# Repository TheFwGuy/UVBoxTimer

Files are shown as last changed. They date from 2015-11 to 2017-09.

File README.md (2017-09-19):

UV Box Timer project

To compile, Set Energia to have the library included and open UVBoxTimer.ino.
This directory should be placed in the main directory where the sketches are
kept.

It is necessary to have these libraries installed in the library directory:

- LCD_protocol_terminal
- LCD_screen
- LiquidCrystal
- SD

Schematics

The schematic used to generate the PCB is under Eagle, UVBoxTimer_g, UVBoxSchematic_r

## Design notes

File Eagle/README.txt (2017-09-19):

The original schematic is under UVBoxTimer.
UVBoxTimer_g is the one created by Roberto in order to prepare the PCB.
So the PCB related schematic is under UVBoxTimer_g, and the schematic is named UVBoxSchematic_r.sch

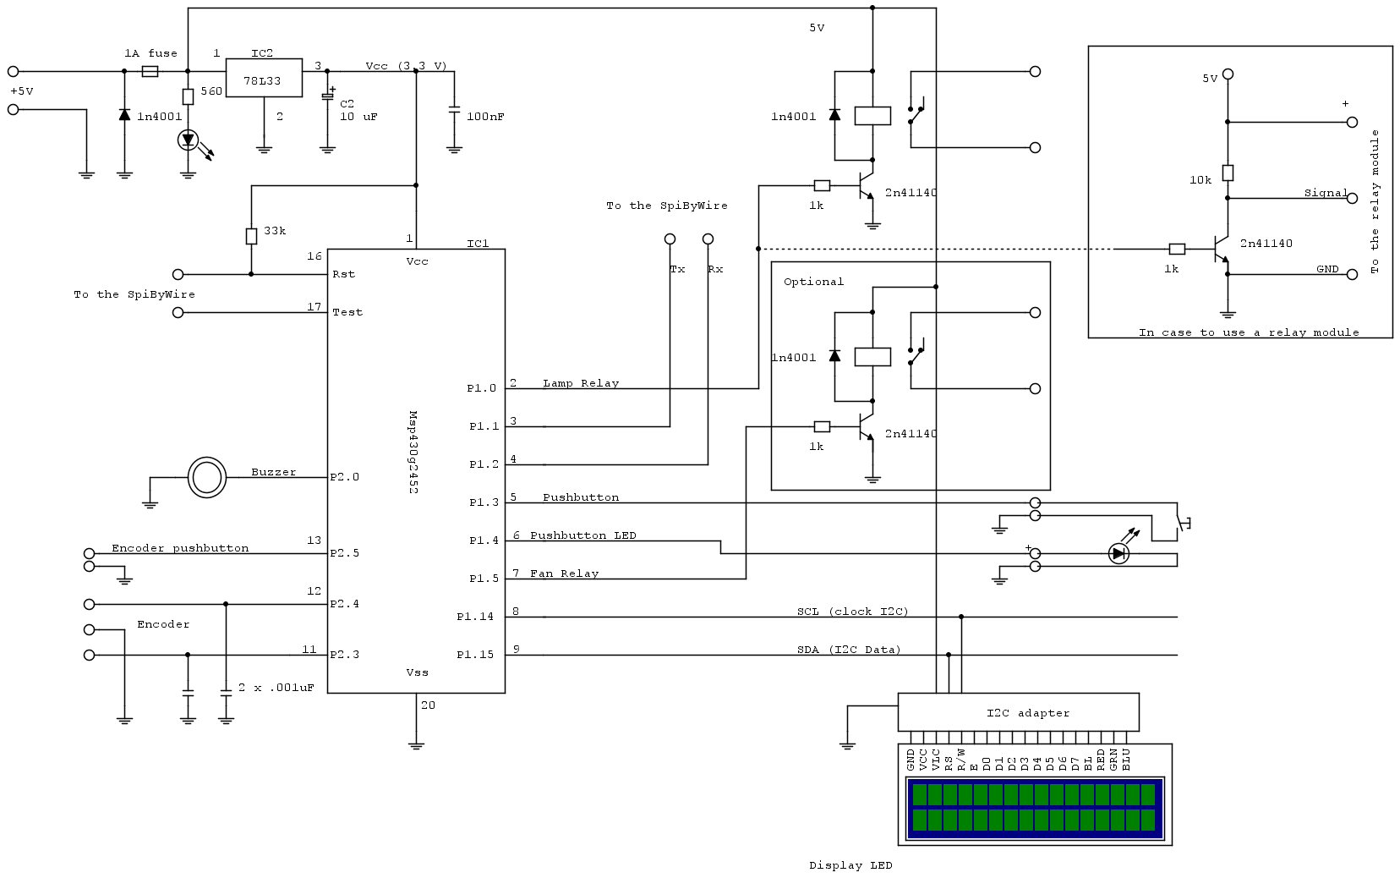
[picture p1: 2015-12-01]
schematic/uvtimer.png

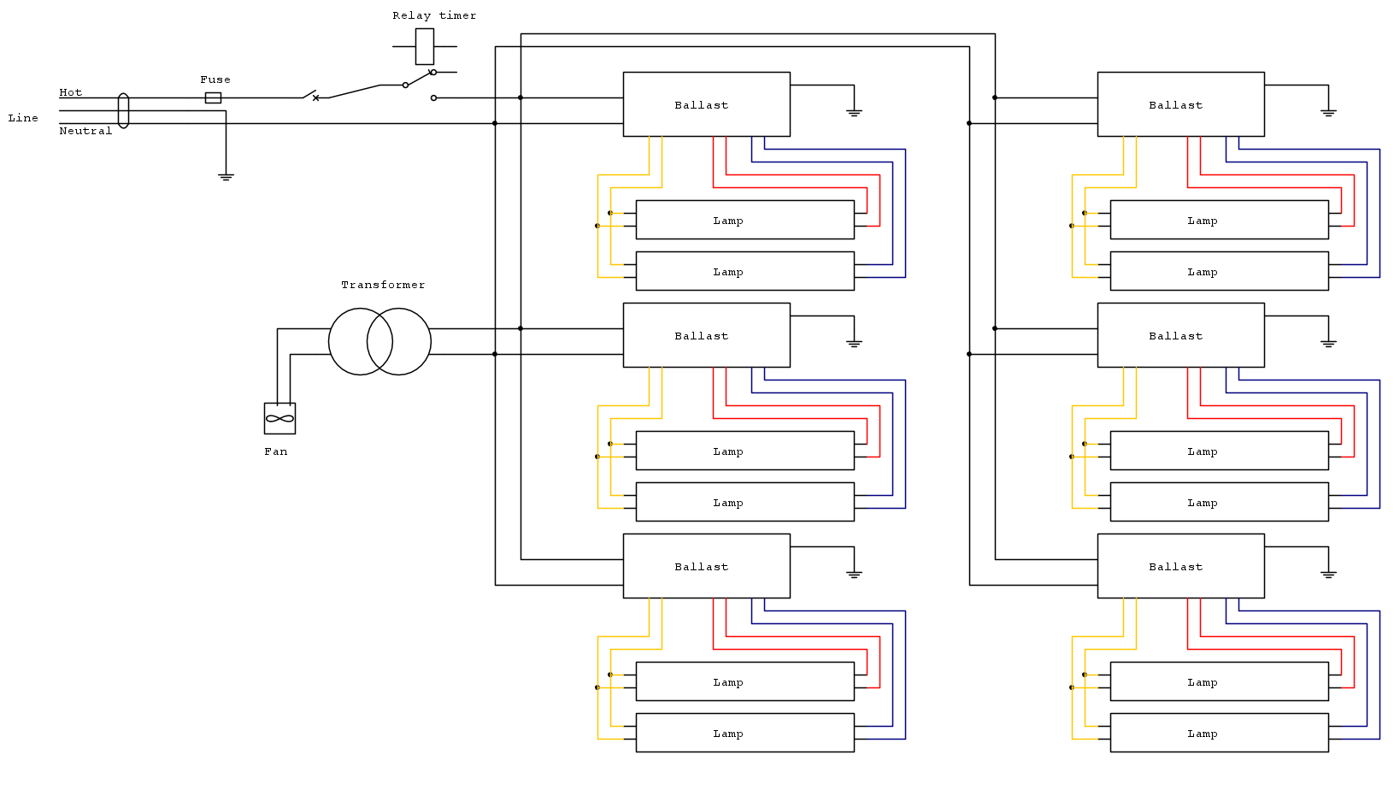
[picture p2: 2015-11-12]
schematic/uvlamps.png

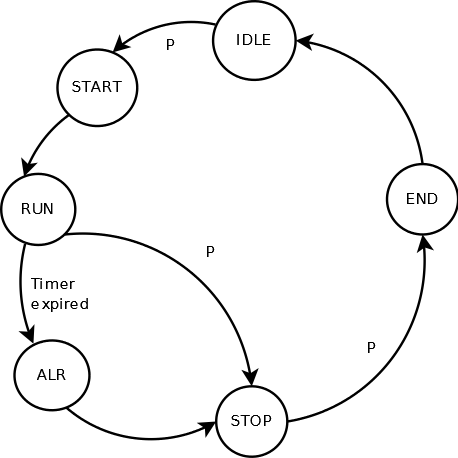
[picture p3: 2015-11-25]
MenuMain.png

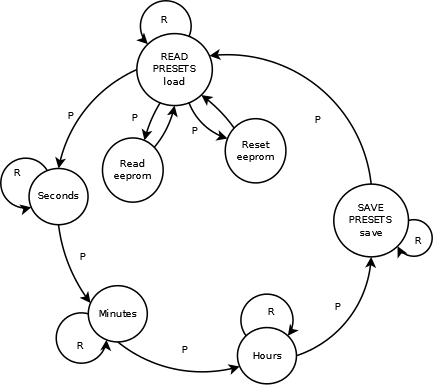
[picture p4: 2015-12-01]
MenuStates.png

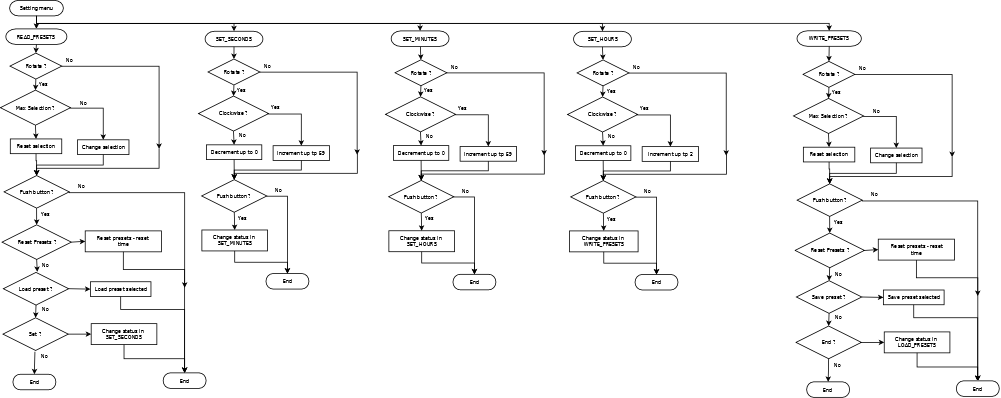
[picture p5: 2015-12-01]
Setting_flow.png

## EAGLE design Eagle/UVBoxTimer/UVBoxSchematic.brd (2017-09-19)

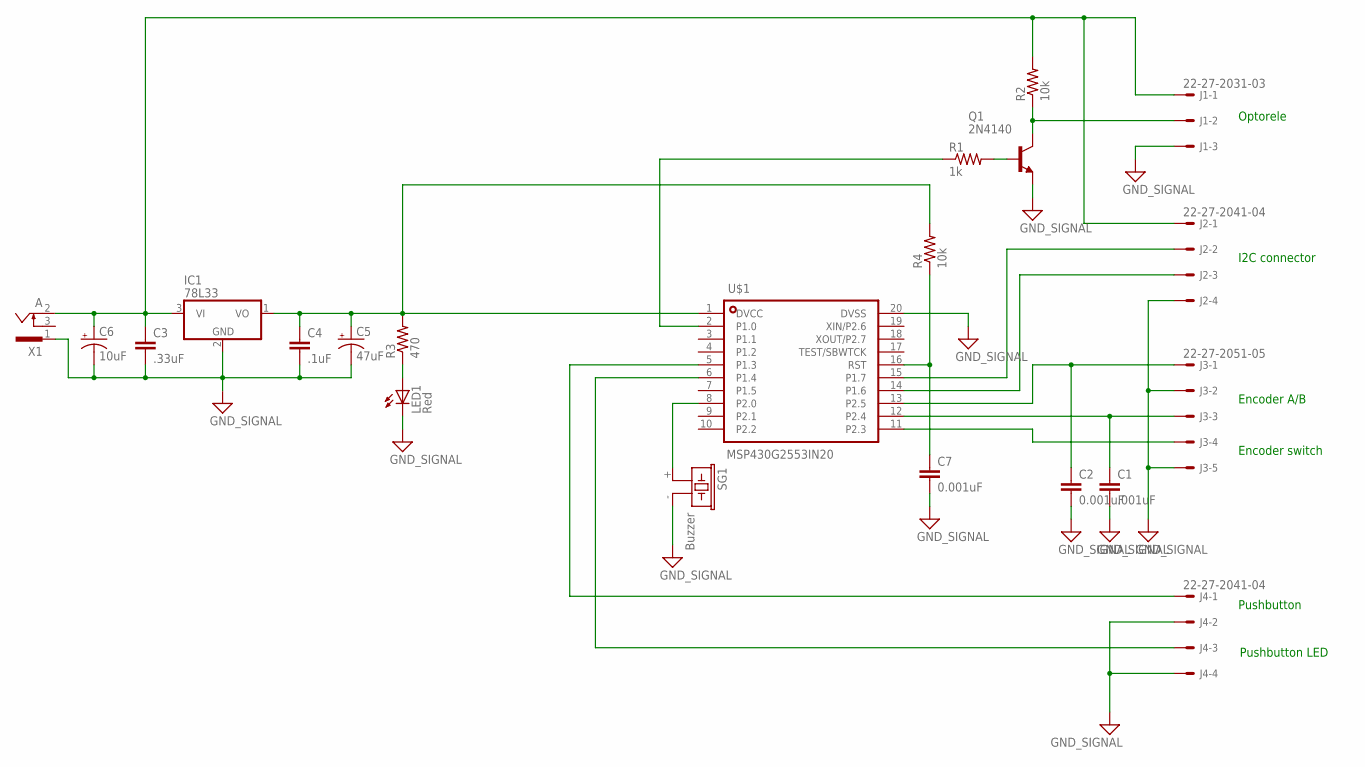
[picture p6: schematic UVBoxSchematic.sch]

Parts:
C1: .001uF; C5B3
C2, C7: 0.001uF; C5B3
C3: .33uF; C5B3
C4: .1uF; C5B3
C5: 47uF; B45181A
C6: 10uF; B45181A
IC1: 78L33; TO92
J1: 22-27-2031-03; 6410-03
J2, J4: 22-27-2041-04; 6410-04
J3: 22-27-2051-05; 6410-05
LED1: Red; LED3MM
Q1: 2N4140; TO18
R1: 1k; 0204/7
R2, R4: 10k; 0204/7
R3: 470; 0204/7
SG1: Buzzer; F/CM04P
U$1: MSP430G2553IN20; DIP20
X1: A; SCD-014-A

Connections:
GND: C1.2, C2.2, C3.2, C4.2, C5.-, C6.-, C7.2, IC1.2 (GND), J1.3, J2.4, J3.2, J3.5, J4.2, J4.4, LED1.K (C), Q1.1 (E), SG1.- (2), U$1.20 (DVSS), X1.1
unnamed: C3.1, C6.+, IC1.3 (VI), J1.1, J2.1, R2.2, X1.2
unnamed: C2.1, J3.1, U$1.13 (P2.5)
unnamed: C1.1, J3.3, U$1.12 (P2.4)
unnamed: J3.4, U$1.11 (P2.3)
unnamed: J2.3, U$1.14 (P1.6)
unnamed: J2.2, U$1.15 (P1.7)
unnamed: LED1.A, R3.1
unnamed: C4.1, C5.+, IC1.1 (VO), R3.2, R4.2, U$1.1 (DVCC)
unnamed: J4.1, U$1.5 (P1.3)
unnamed: J1.2, Q1.3 (C), R2.1
unnamed: Q1.2 (B), R1.2
unnamed: R1.1, U$1.2 (P1.0)
unnamed: J4.3, U$1.6 (P1.4)
unnamed: SG1.+ (1), U$1.8 (P2.0)
unnamed: C7.1, R4.1, U$1.16 (RST)

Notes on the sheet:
Encoder A/B
Encoder switch
I2C connector
Optorele
Pushbutton
Pushbutton LED

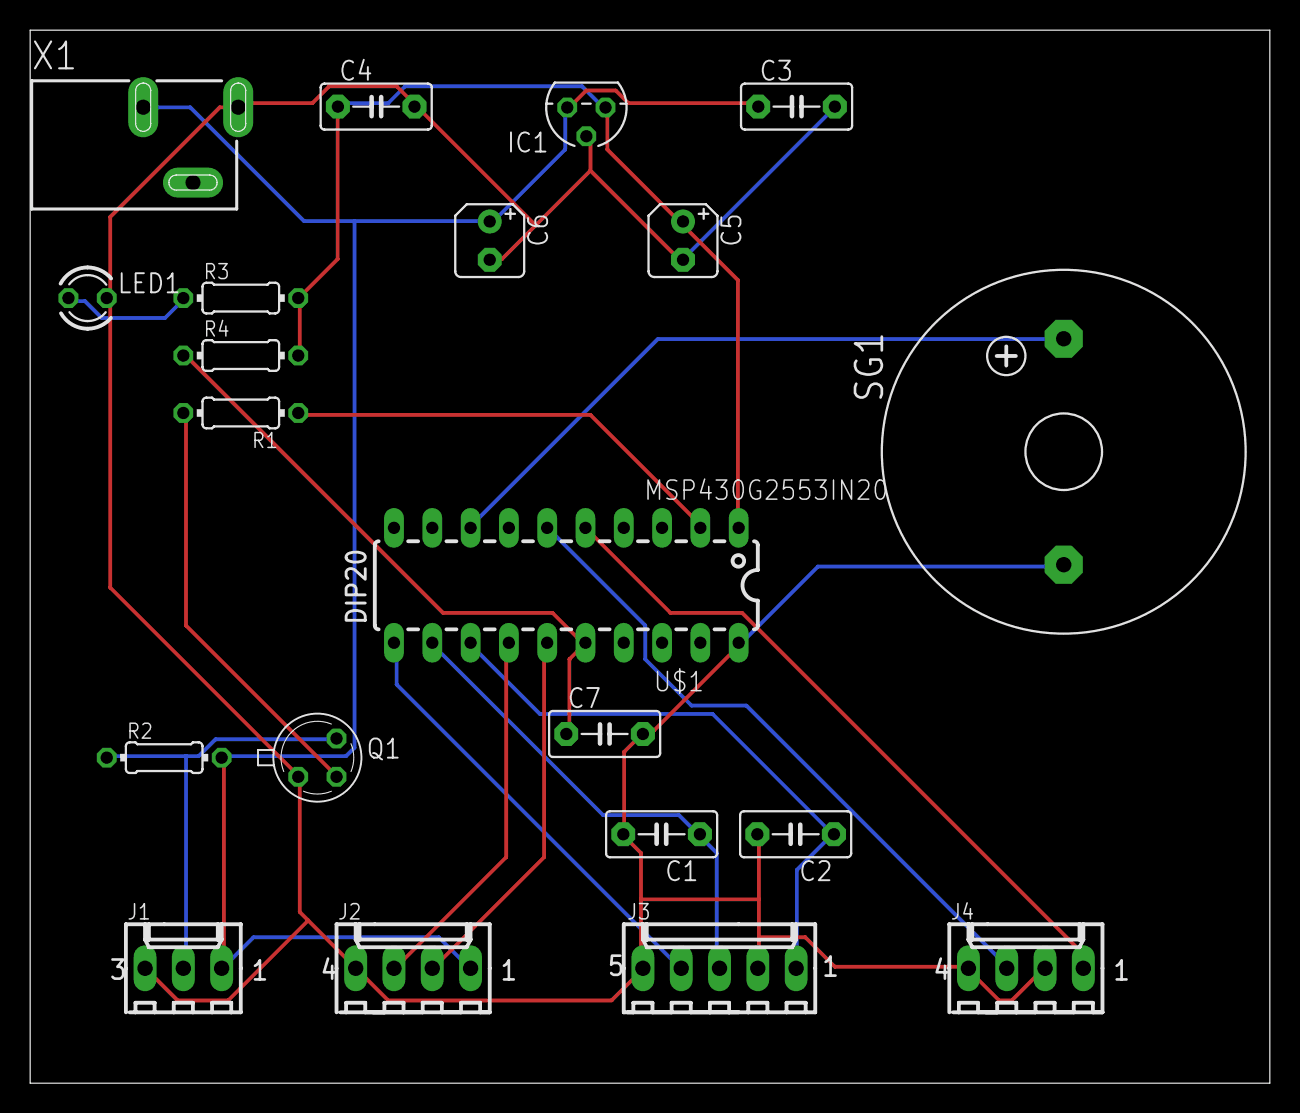
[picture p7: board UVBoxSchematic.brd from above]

Board: 2 copper layers, 82.2 x 69.8 mm, 21 parts (0 on the bottom side), 16 nets.

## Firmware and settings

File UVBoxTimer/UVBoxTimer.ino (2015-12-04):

/**
 *  UV Box Timer project
 *  @Auth Roberto Romano
 *  @Auth TheFwGuy
 *  November 2015
 *  @Brief Timer to control 12 UV fluorescent lamps with MSP430g2553
 *
 *  A LCD display, 16 x 2, is used to display information.
 *  The top line shows always the timer value.
 *  The bottom line shows menu' and indications.
 *
 */

#include <Wire.h>
#include <LCD.h>
#include <LiquidCrystal_I2C.h>  // F Malpartida's NewLiquidCrystal library
#include "MspFlash.h"

/* Function prototypes */

void settingManagement();
void displaySetting();
void secondsToTime(int, short *, short *, short * );
void displayTime(short, short, short);
void displayMenu();
int timeToSeconds(int , int , int );
unsigned char waitingResetTimer(unsigned char);

/* 
 *  I2C display defines
 */
 
#define I2C_ADDR 0x3F
#define BACKLIGHT_PIN  3

#define Rs_pin  0
#define Rw_pin  1
#define En_pin  2
#define D4_pin  4
#define D5_pin  5
#define D6_pin  6
#define D7_pin  7

LiquidCrystal_I2C  lcd(I2C_ADDR,En_pin,Rw_pin,Rs_pin,D4_pin,D5_pin,D6_pin,D7_pin, BACKLIGHT_PIN, POSITIVE);

/*
 *  Generic defines
 */
#define  OFF  0
#define  ON  1

#define DISPLAY_TIME	/* Comment this out in order to display seconds countdwon */

#define MAX_PRESET	10  /* Max number of preset values handled */

#define BURNS_ENCODER    /* If defined the encoder used is the burns one (from Adafruit) - if not defined is the one from All Electronics */

/* Main state machine states defines */

#define IDLE  0
#define START 1
#define RUN   2
#define ALR   3
#define STOP  4
#define END   5

/* Setting state machine states defines */

#define READ_PRESETS  0
#define SET_SECONDS   1
#define SET_MINUTES   2
#define SET_HOURS     3
#define SAVE_PRESETS  4

/*
 *  I/O defines
 */

#define RELAY_LAMP 2		/* P1_0 */

#define STARTBTN   5        /* P1_3 */
#define STARTLED   6        /* P1_4 */
#define RELAY_FAN  7	    /* P1_5 */

#define BUZZER     8        /* P2_0 */

#define SELBTN     13       /* P2_5 */

// warning port name is supported by digital read but interrupt is not using it encoder is connected to pin 19 and 18
#define ENC_A   P2_4
#define ENC_B   P2_3

/*
 *  Macro defines
 */
 
#define KEYIsPressed(key) (!digitalRead(key))
#define KEYIsNotPressed(key) (digitalRead(key))

/*
 I2C mode 
 SDA P1_7 Pin 14
 SCL P1_6 Pin 13 
*/

/*
 *  Flash define
 *  Uses Segment D - 64 bytes - 2 bytes for a time - max allowed 32 presets
 *  Used only 10 presets
 */
#define flash SEGMENT_D 

/*
 *  Global variables
 */

long TimerTimeSec; // actual millis when timer elapse

int EncoderRead=0;
int oldEncoderRead=0;

int TimerSecCounter; 

short hour = 0;
short minute = 0;
short second = 0;

char buffer[20];

unsigned char saving_flag = 0;		        /* 0 - don't save - 1 - save */
unsigned char toggle_LED = 0;
unsigned char main_status = IDLE;
unsigned char set_status  = READ_PRESETS;
unsigned char force_display_setting = OFF;
unsigned char force_display_title = OFF;         /* 1 display the title */
unsigned char preset_index = 0;

const char time_menu[]   = "Time            ";
const char logo_menu[]   = "UVBox Timer 1.0 ";
const char preset_menu[] = "Preset #        ";
const char select_menu[] = "Set             ";
const char run_menu[]    = "Action:         ";


/**
 *  @fn doEncoder
 *  @brief Interrupt service encoder function 
 *  The read has an upper limt to 80 and a lower limit of 0
 */

void doEncoder() 
{
   /* Only in IDLE is allowed to set up */
   if(main_status != IDLE)
      return;

   /* If pinA and pinB are both high or both low, it is spinning
    * forward. If they're different, it's going backward.
    *
    * For more information on speeding up this process, see
    * [Reference/PortManipulation], specifically the PIND register.
    */
   if (digitalRead(ENC_A) == digitalRead(ENC_B)) 
   {
      if(EncoderRead<80)
         EncoderRead++;
   }
   else 
   {
      if(EncoderRead>0)
         EncoderRead--;
   }
}

void setup()
{
  // put your setup code here, to run once:
  pinMode(RELAY_LAMP,OUTPUT);
  digitalWrite(RELAY_LAMP,LOW); // switch off
  
  pinMode(STARTBTN,INPUT_PULLUP);
  pinMode(STARTLED,OUTPUT);
  digitalWrite(STARTLED,LOW); // Pushbutton LED off

  pinMode(SELBTN,INPUT_PULLUP);
  pinMode(ENC_A,INPUT_PULLUP);
  pinMode(ENC_B,INPUT_PULLUP);

  pinMode(BUZZER,OUTPUT);

  lcd.setBacklightPin(BACKLIGHT_PIN, POSITIVE); // POSITIVE); //NEGATIVE);
  lcd.setBacklight(ON);
  lcd.backlight();
    
  lcd.begin(16,2);               // initialize the lcd 

  lcd.clear();
  lcd.home ();                   // go home
  lcd.display();
  lcd.print(time_menu);  
  lcd.setCursor ( 0, 1 );        // go to the next line
  lcd.print (logo_menu);      
  
  displayTime(hour, minute, second);        

   /* 
    *  The BURNS encoder needs generates a rising signal for each dent, the AllElectronic encoder generates a change signal
    *  for each dent
    */
#if defined(BURNS_ENCODER)
  attachInterrupt(ENC_A,doEncoder,RISING);
#else
  attachInterrupt(ENC_A,doEncoder,CHANGE);
#endif  
}


void loop()
{
   short run_hour;
   short run_minute;
   short run_second;
   // put your main code here, to run repeatedly:
   // setup loop

   /*
    *  Main state machine
    *  Note that the pushbutton is active on the RELEASE not when pushed.
    */
   switch(main_status)
   {
      case IDLE:
         settingManagement();		/* Handle settings */
		 
         if(KEYIsPressed(STARTBTN) && !(hour==0 && minute == 0 && second == 0))
         {
            while(KEYIsPressed(STARTBTN));  /* Wait until the button is released */
            
            main_status = START;
            force_display_title = ON;
         }
         break;
         
      case START:   
         // timer loop
         TimerTimeSec=millis(); // timer value to actual time to display timer and decrement seconds
         TimerSecCounter=timeToSeconds(hour, minute,second)+1; // add one to account for first update

         digitalWrite(RELAY_LAMP,HIGH); // switch on
         digitalWrite(STARTLED,HIGH);   // Pushbutton LED on
         
         main_status = RUN;
         break;
      
      case RUN:  
         // test 1 second has elapsed 
         if(millis()>TimerTimeSec) // 1 second elapsed
         {
            TimerTimeSec=millis()+1000;
            TimerSecCounter--;

            secondsToTime(TimerSecCounter, &run_hour, &run_minute, &run_second);
            
            displayTime(run_hour, run_minute, run_second);        
         }
            
         if(KEYIsPressed(STARTBTN))
         {
            while(KEYIsPressed(STARTBTN));  /* Wait until the button is released */

            digitalWrite(RELAY_LAMP,LOW); // switch off
            digitalWrite(STARTLED,LOW);   // Pushbutton LED off
                      
            main_status = STOP;
         }
         else if(TimerSecCounter == 0)
         {
            digitalWrite(RELAY_LAMP,LOW); // switch off
            digitalWrite(STARTLED,LOW);   // Pushbutton LED off
          
            main_status = ALR;
         }
         break;
             
      case ALR:
         tone(BUZZER, 550);            /* Emit tone */
         main_status = waitingResetTimer(main_status);
	 break;
      
      case STOP:
         main_status = waitingResetTimer(main_status);
         break;
         
      case END:      
         noTone(BUZZER);                  /* Stop tone */
         force_display_setting = 1;   
      
//         lcd.setCursor ( 0, 1 );        // go to the next line
//         lcd.print ("Action: END     ");       
   
         EncoderRead = second;      // Set default on last second value 
         oldEncoderRead = second;

         main_status = IDLE;
         set_status  = SET_SECONDS;
         
         displayTime(hour, minute, second);        
         break;
   }
   
   displayMenu();
}



/**
 *  @fn displayTime
 *  @brief Display the time on the first LCD line
 *  @param hours - value for hours
 *  @param minutes - value for minutes
 *  @param seconds - value for seconds
 */
void displayTime(short hours, short minutes, short seconds)
{
   lcd.setCursor ( 7, 0);        /* Go after the writing Time */
   lcd.print("     ");

#if defined(DISPLAY_TIME)
   lcd.setCursor ( 7, 0);        
   sprintf(buffer, "%02d:%02d:%02d", hours, minutes, seconds);
   lcd.print(buffer);         
#else
   lcd.setCursor ( 10, 1);        
   lcd.print(TimerSecCounter);     
#endif
}

/**
 *  @fn displayMenu
 *  @brief Display the menu on the second LCD line
 *  The function uses a flag to know when to display the title.
 */
void displayMenu()
{
   short tmp_value = 0;
   
   if(main_status == IDLE)
   {
      if(force_display_title)
      {
         lcd.setCursor ( 0, 1 );        /* Position on the second line */
         force_display_title = OFF;
         /* Display menu title */
         switch(set_status)
         {
            case READ_PRESETS:
            case SAVE_PRESETS:
               lcd.print (preset_menu);
               break;
            case SET_SECONDS:
            case SET_MINUTES:
            case SET_HOURS:
               lcd.print (select_menu);
	       break;
         }
      }   

      /* Display menu value */
      switch(set_status)
      {
         case READ_PRESETS:
            break;
         case SET_SECONDS:
            lcd.setCursor ( 4, 1 );        /* Position on the second line */
            lcd.print ("Seconds  ");
            break;
         case SET_MINUTES:
            lcd.setCursor ( 4, 1 );        /* Position on the second line */
            lcd.print ("Minutes  ");
            break;
         case SET_HOURS:
            lcd.setCursor ( 4, 1 );        /* Position on the second line */
            lcd.print ("Hours    ");
            break;
         case SAVE_PRESETS:
            lcd.setCursor ( 9, 1 );        /* Position on the second line */
            if(preset_index <= MAX_PRESET)
            {
               lcd.print(preset_index);
            }
            else
               lcd.print(" res");
            break;
      }
   }
   else
   {
      if(force_display_title)
      {
         lcd.setCursor ( 0, 1 );        /* Position on the second line */
         lcd.print (run_menu);
         force_display_title = OFF;
      }        
      
      lcd.setCursor ( 8, 1 );        /* Position on the second line */  
	   
      switch(main_status)
      {
         case STOP:
            lcd.print("STOP");
            break;
         case ALR:
            lcd.print("END ");
            break;
         default:		 
            lcd.print("RUN ");
            break;
      }
   }
}



/**
 *  @fn settingManagement
 *  @brief setting state machine management
 *  This state machine is working only when the main state machine is in IDLE, otherwise it is never called.
 */
void settingManagement()
{
   unsigned char enc_read = OFF;
   unsigned char btn_read = OFF;

   /* Reading selection push button status */
   if(KEYIsPressed(SELBTN))
   {
      while(KEYIsPressed(SELBTN));
	  btn_read = ON;
   }

   /* Determine if there is an encoder change value */   
   if(oldEncoderRead != EncoderRead )
   {
      enc_read = ON;	 
   }
   
   /* Continue only if there is an action */
   if(!enc_read && !btn_read)
      return;
	  
   switch(set_status)
   {
      case READ_PRESETS:
         force_display_title = ON;
         if(enc_read)
         {
            /*
             *  The preset_index meaning :
             *  0 - 10 -> preset index - 0 indicates no loading
             *  11     -> Set time
             */
            if(EncoderRead > MAX_PRESET+1)
               EncoderRead = MAX_PRESET+1;
            preset_index = EncoderRead;		 
        }
		 
        if(btn_read)
        {
	
           /* Execute action */
        }
        break;
		 
      case SET_SECONDS:
         if(enc_read)
         {
            if(EncoderRead > 59)
               EncoderRead = 59;
            second = EncoderRead;   
         }
		 
         if(btn_read)
         {
            /* 
             *  Button pressed - prepare for the setting of minutes
             */
            EncoderRead = minute;
            oldEncoderRead = minute;
            set_status = SET_MINUTES;
         }
         break;

      case SET_MINUTES:
         if(enc_read)
         {
            if(EncoderRead > 59)
               EncoderRead = 59;
            minute = EncoderRead;   
         }

         if(btn_read)
         {
            /* 
             *  Button pressed - prepare for the setting of hours
             */
            EncoderRead = hour;
            oldEncoderRead = hour;
	    set_status = SET_HOURS;
         }
         break;

      case SET_HOURS:
         if(enc_read)
         {
            if(EncoderRead > 2)
               EncoderRead = 2;
            hour = EncoderRead;   
         }
		 
         if(btn_read)
         {
            EncoderRead = preset_index;
            oldEncoderRead = preset_index;
            set_status = SAVE_PRESETS;
         }
         break;
		 
      case SAVE_PRESETS:
         if(enc_read)
         {
            /*
             *  The preset_index meaning :
             *  0 - 10 -> preset index - 0 indicates no saving and change state
             *  11     -> reset flash memory
             */
            if(EncoderRead > MAX_PRESET+1)
               EncoderRead = MAX_PRESET+1;
            preset_index = EncoderRead;		 
         }

         if(btn_read)
         {
            if(preset_index == 0)
            {
               /* Do nothing - change state */
               set_status = READ_PRESETS;
            }
            else if(preset_index >= 1 && preset_index <= MAX_PRESET)
            {
               /* Save current value in preset indexed - TBD */
			   
            }
            else
            {
              		   /* Reset flash memory */
            }
	 }
         break;
   }
}

/*-------------------- Utility functions ---------------------------------------*/

/*
 *  @fn waitingResetTimer
 *  @brief Wait for the push button pressing. Returns the next state, current one or END
 */
unsigned char waitingResetTimer(unsigned char status)
{
   /* Waiting to press the button */
         
   if(toggle_LED)
   {
      digitalWrite(STARTLED,LOW);   // Pushbutton LED off
      toggle_LED=OFF;
   }
   else
   {
      digitalWrite(STARTLED,HIGH);   // Pushbutton LED on
      toggle_LED=ON;
   }
   delay(200);
                
   if(KEYIsPressed(STARTBTN))
   {
      while(KEYIsPressed(STARTBTN));  /* Wait until the button is released */

      digitalWrite(STARTLED,LOW);   // Pushbutton LED off
      return(END);
   }
   return(status);
}


/**
 *  @fn secondsToTime
 *  @brief The function has the purpose to convert a single value in seconds into
 *  the more traditional hours/minutes/seconds display
 *  @param raw_seconds - number of seconds to convert
 *  @param hours - pointer to the location where to store the hour value
 *  @param minutes - pointer to the location where to store the minutes value
 *  @param seconds - pointer to the location where to store the seconds value
 *  No return value
 */
void secondsToTime(int raw_seconds, short *hours, short *minutes, short *seconds )
{
   int temp=0;

   *hours = raw_seconds/3600;
   temp = *hours * 3600;
   *minutes = (raw_seconds - temp)/60;
   temp += *minutes * 60;
   *seconds = raw_seconds - temp;
}

/*
 *  @fn timeToSeconds
 *  @brief The function has the purpose to create a single value in seconds from hour/minutes/seconds
 *  @param hours - value of hours, from 0 to 2
 *  @param minutes - value of minutes, from 0 to 59
 *  @param seconds - value of seconds, from 0 to 59
 *  Return the number of seconds
 */
int timeToSeconds(int hours, int minutes, int seconds )
{
   int raw_seconds;
   
   raw_seconds = (hours * 3600) + (minutes * 60) + seconds;
   
   return(raw_seconds);
}



/*
 * ----------- OLD functions ----- to be deleted -------------------------------- 
 */
#if 0 
/*
 *  settingManagement function
 *  This function manage the setting state machine.
 *  This state machine is working only when the main state machine is in IDLE, otherwise it is never called.
 */
void settingManagement()
{
   displaySetting();

   if(KEYIsPressed(SELBTN))
   {
      while(KEYIsPressed(SELBTN));
                         
      force_display_setting = 1;   

      switch(set_status)
      {
         case SET_SECONDS:
            EncoderRead = minute;
            oldEncoderRead = minute;
            break;

         case SET_MINUTES:
            EncoderRead = hour;
            oldEncoderRead = hour;
            break;

         case SET_HOURS:
            EncoderRead = 1;
            oldEncoderRead = 1;
            saving_flag = 1;
            break;
 
        case READ_PRESETS:
        case SAVE_PRESETS:
            EncoderRead = second;
            oldEncoderRead = second;
			
	    /* Button pushed in this state - if flag OK save value in eeprom */
            if(saving_flag)
	    {
	       /* TBD - save value in eeprom */
	       saving_flag = 0;
	    }
	    break;
       }     

       set_status++;
       if(set_status > SAVE_PRESETS)
          set_status = READ_PRESETS;
	  
   }
}

/*
 *  displaySetting function
 *  This function manage the setting state machine.
 *  This state machine is working only when the main state machine is in IDLE, otherwise it is never called.
 */
void displaySetting()
{
   if(oldEncoderRead != EncoderRead || force_display_setting)
   {
      force_display_setting = 0;

      lcd.setCursor ( 0, 1 );        // go to the next line
      switch(set_status)
      {
         case SET_SECONDS:
            lcd.print ("Set Seconds     ");
            if(EncoderRead > 59)
               EncoderRead = 59;
            second = EncoderRead;   
            break;

         case SET_MINUTES:
            lcd.print ("Set Minutes     ");
            if(EncoderRead > 59)
               EncoderRead = 59;
            minute = EncoderRead;   
            break;

         case SET_HOURS:
            lcd.print ("Set Hours       ");
            if(EncoderRead > 2)
               EncoderRead = 2;
            hour = EncoderRead;   
            break;

	case SAVE_PRESETS:
	    switch(EncoderRead)
            {
	       case 0:
                  lcd.print ("Save ?      No  ");
                  break;+++
	      case 1:
                  lcd.print ("Save ?      Yes ");
		  break;		  
	    }
			
            if(EncoderRead > 1)
               EncoderRead = 1;
            saving_flag = EncoderRead;   
            break;
       }
     
      oldEncoderRead=EncoderRead;
      
      displayTime(hour, minute, second);
          
   }
}


#endif

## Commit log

2015-11-12 Added schematics
2015-11-12 Selected I2C mode - little bit clean up
2015-11-12 Removed pull ups - are set in the pin
2015-11-13 Restored lcd.print(value)
2015-11-13 Removed sprintf - replaced with lcd.print(value)
    [UVBoxTimer.ino]
2015-11-13 set increment of 5 - prevented change param during run
    [UVBoxTimer.ino]
2015-11-14 Fixed encoder/pushbutton reading - changed messages - other fixing
    [UVBoxTimer.ino]
2015-11-14 Changed menu' - display - UI interface - big enhancements - fixed encoder-pushbutton readings
    [UVBoxTimer.ino]
2015-11-17 Added Pushbutton LED management
2015-11-17 Added 2 .001uF capacitor for encoder
2015-11-17 Added relays
2015-11-28 Changed management for different encoder
2015-11-30 start flow new state machine
2015-12-01 Flow for setting menu
2015-12-01 update schematic to latest tests
2017-09-19 Added Eagle schematics
    [UVBoxSchematic.brd, UVBoxSchematic.sch, UVBoxSchematic_1.0.brd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]
2017-09-20 Removed duplicate schematics
    [UVBoxSchematic.brd, UVBoxSchematic.sch]
